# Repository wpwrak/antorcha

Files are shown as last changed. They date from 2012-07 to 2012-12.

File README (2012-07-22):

Antorcha - A LED-based signal device
====================================

...

Directory placement
-------------------

Antorcha makes extensive use of libraries and header of the ben-wpan
project. For this, the top-level directory of the ben-wpan project must
be in the same directory as the top-level directory of Antorcha. E.g.,

/home/qi/ben-wpan/
/home/qi/antorcha/

Avrdude configuration
---------------------

Antorcha uses the atusb programming adapter from the ben-wpan project.
Since the pin positions of MISO and MOSI are swapped between ATmega32U2
and the ATmega168, we use a modified configuration entry.

It is passed to avrdude via the new -L option, available with the
Nanonote patches at

http://projects.qi-hardware.com/index.php/p/ben-blinkenlights/source/tree/master/avrdude

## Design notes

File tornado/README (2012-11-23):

Tornado - A LED-based signal device
===================================

Tornado displays text or images with a line of 64 individually
controllable LEDs. To produce 2D images, the line is manually
rotated.

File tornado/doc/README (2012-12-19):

Antorcha vs. Tornado feature comparison
---------------------------------------

Number of LEDs		32			64
Pixels			16			64
LED pitch		8 mm			5 mm
1 arc sec / pixel (1)	28 m			17 m
1 arc sec / text (2)	70 m			90 m
LED line length		25 cm			32 cm
Total stick length	63 cm			53 cm (TBD)
Outer radius		~ 90 cm			~ 80 cm (3)
Visible width		~ 100 cm		~ 110 cm (3)
Sweeps per second	~ 4, bidirectional	~ 3, unidirectional
Sweep speed (avg.)	~ 8 m/s			~ 15 m/s (3)

(1) http://en.wikipedia.org/wiki/Visual_acuity
(2) 2 text lines, 1/12 display height
(3) for chain length = 30 cm

Weight
------

Al stick: 52.5 g / 52.7 cm = ~ 1 g/cm
Chain:	44 g / 19 links = ~ 2.3 g/link
	305 mm / 21 links = 14.5 mm/link
	1.6 g/cm
Attachment (screw, washers, nut): 2.3 g
End cap: 1.54 g
Cable:	1.74 g / 382 mm
	group of 3: ~ 0.14 g/cm
LED PCB: 4.1 g
CPU PCB: 4.5 g

Not included in the weight calculation:
- glue
- adhesive tapes
- isolation tapes
- cable binders (if any)
- heat-shrink tubing
- cables/wires for inter-board connections

Update rate
-----------

For square pixels we need one update every 5 mm. With the edge moving
at 15 m/s, that's one update every 1/3000 s. If we assume that,
including overhead, each 64 bit shift and latch takes about 100 clock
cycles, the serial bus needs to run at no less than 300 kHz.

sclk-1123.png shows the ~250 ns clock pulse generated by the current
test firmware. CH2 (blue) is signal entering the first LED module,
CH1 (yellow) is the signal exiting the last module. The absence of
degradation in a 250 ns pulse suggests that we can go as fast as the
MCU is able to.

Image size
----------

With a radius of 80 cm the circumference is roughly 5000 mm.
In order to obtain square pixels at the outer radius, we therefore
need 1000 lines per rotation, irrespective of speed. Each line
consists of 64 pixels or 8 bytes of data. Therefore, the full disc
needs roughly 8 kB of data while a quarter disc needs 2 kB.

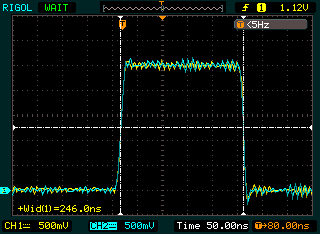
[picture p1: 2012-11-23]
tornado/doc/sclk-1123.png

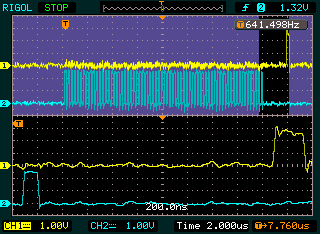
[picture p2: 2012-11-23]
tornado/doc/lclk-1123.png

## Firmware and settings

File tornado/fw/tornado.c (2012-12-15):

#include <stdbool.h>
#include <stdint.h>

#include <avr/interrupt.h>
#include <avr/pgmspace.h>
#define F_CPU   8000000UL
#include <util/delay.h>

#include "io.h"
#include "led.h"
#include "mmc.h"
#include "accel.h"


#define	HIGH(port) \
	(MASK(port, CARD_nPWR) | \
	MASK(port, SW_N) | MASK(port, SW_E) | MASK(port, SW_S) | \
	MASK(port, SW_W) | MASK(port, SW_SW))

#define	OUTPUTS(port) \
	(MASK(port, CARD_nPWR) | MASK(port, CARD_CLK) | \
	MASK(port, LED_DS) | MASK(port, LED_LCLK) | MASK(port, LED_SCLK))


#if 0

/*
 * @@@ For testing, connect the LED bar via the 8:10 card slot, so that it
 * can be disconnected without soldering.
 */

#define	SCLK	CARD_DAT1
#define	LCLK	CARD_DAT0
#define	DS	CARD_CLK
#define	VDD	CARD_CMD

#else

#define	SCLK	LED_SCLK
#define	LCLK	LED_LCLK
#define	DS	LED_DS

#endif


static void send(uint8_t pattern[N_LEDS/8])
{
	uint8_t i, j, mask;

	for (i = 0; i != N_LEDS/8; i++) {
		mask = 1;
		for (j = 0; j != 8; j++) {
			if (pattern[i] & mask)
				SET(DS);
			else
				CLR(DS);
			SET(SCLK);
			CLR(SCLK);
			mask <<= 1;
		}
	}
	SET(LCLK);
	CLR(LCLK);
}


static inline void admux(bool x)
{
	ADMUX =
	    1 << REFS0 |	/* Vref is AVcc */
	    (x ? ADC_X : ADC_Y);
}


static inline void adcsra(bool start)
{
	/*
	 * The ADC needs to run at clkADC <= 200 kHz for full resolution.
	 * At clkADC = 125 kHz, a conversion takes about 110 us.
	 */
	ADCSRA =
	    1 << ADEN |		/* enable ADC */
	    (start ? 1 << ADSC : 0) |
	    1 << ADIE |         /* enable ADC interrupts */
	    6;                  /* clkADC = clk/64 -> 125 kHz */
}


static uint16_t adc(bool x)
{
	adcsra(0);
	admux(x);
	adcsra(1);
	while (ADCSRA & (1 << ADSC));
	return ADC;
}


#define	E_SHIFT	8	/* ~ 0.06 */
#define	M_SHIFT	11	/* ~ 2/sample_rate */

#define	HYSTERESIS	9	/* 1 g / 3 */


static const uint8_t img[] PROGMEM = {
	#include "img.inc"
};


static uint8_t one[LED_BYTES] =
    { 0xff, 0xff, 0xff, 0xff, 0xff, 0xff, 0xff, 0xff };

static volatile uint16_t sample_t = 0, sample_v;


static void zxing(uint16_t x, uint16_t y)
{
	static uint32_t e = (uint32_t) 512 << E_SHIFT;
	static uint32_t m = (uint32_t) 512 << M_SHIFT;
	int16_t d;
	static bool up = 0;
	static bool on = 0;
	static const prog_uint8_t *p;
	static uint16_t cols = 0;

	sample_t++;
	sample_v = x;

	e = x+(e-(e >> E_SHIFT));
	m = x+(m-(m >> M_SHIFT));
	d = (e >> E_SHIFT)-(m >> M_SHIFT);
	if (up) {
		if (d < -HYSTERESIS)
			up = 0;
	} else {
		if (d > HYSTERESIS) {
			up = 1;
			p = img;
			cols = sizeof(img)/LED_BYTES;
			on = 1;
		}
	}
	if (cols) {
		led_show_pgm(p);
		p += 8;
		cols--;
	} else {
		led_off();
	}
}


static void panic(void)
{
	cli();
	while (1) {
		led_show(one);
		_delay_ms(100);
		led_off();
		_delay_ms(100);
	}
}


int main(void)
{
	PORTB = HIGH(B);
	PORTC = HIGH(C);
	PORTD = HIGH(D);
	DDRB = OUTPUTS(B);
	DDRC = OUTPUTS(C);
	DDRD = OUTPUTS(D);

	CLR(CARD_nPWR);
	CLR(SCLK);
	CLR(LCLK);
	OUT(SCLK);
	OUT(LCLK);
	OUT(DS);

#ifdef VDD
	SET(VDD);
	OUT(VDD);
#endif

	led_init();

#if 0
	led_show(one);

	if (!mmc_init())
		panic();
	if (!mmc_begin_write(0))
		panic();

	uint16_t n = 0;

	for (n = 0; n != 512; n += 2) {
		mmc_write(n);
		mmc_write(n >> 8);
	}

	if (!mmc_end_write())
		panic();

	if (!mmc_begin_write(n))
		panic();

	for (; n != 1024; n += 2) {
		mmc_write(n);
		mmc_write(n >> 8);
	}

	if (!mmc_end_write())
		panic();

	_delay_ms(1000);

	led_off();

	while (1);
#endif

#if 1
	uint16_t last_t = 0;
	uint32_t n = 0;

	sample = zxing;
	/* MMC doesn't work when running from battery, probably because we
	   have no regulation. Just disable it for now. */
#if 0
	if (!mmc_init())
		panic();
#endif
	accel_start();
	sei();
while (1);
	while (1) {
		uint16_t t, v;

		if (!(n & 511)) {
			if (n && !mmc_end_write())
				panic();
			if (!mmc_begin_write(n))
				panic();
		}

#if 0
	t = n;
	v = 0;
#else
		do {
			cli();
			t = sample_t;
			v = sample_v;
			sei();
		}
		while (t == last_t);
#endif

		last_t = t;
		mmc_write(t);
		mmc_write(t >> 8);
		mmc_write(v);
		mmc_write(v >> 8);
		n += 4;
	}
#endif

#if 0
	static uint8_t p[LED_BYTES];
	uint8_t mode = 0;
	uint16_t n = 0, v;

	while (1) {
		while (!PIN(SW_SW));
		if (!PIN(SW_N))
			mode = 0;
		if (!PIN(SW_E))
			mode = 1;
		if (!PIN(SW_S))
			mode = 2;
		switch (mode) {
		case 1:
			n = adc(0);
			p[0] = n;
			p[1] = n >> 8;
			p[2] = p[3] = p[4] = p[5] = p[6] = p[7] = 0;
			send(p);
			break;
		case 2:
			n = adc(1);
			p[0] = n;
			p[1] = n >> 8;
			p[2] = p[3] = p[4] = p[5] = p[6] = p[7] = 0;
			send(p);
			break;
		default:
			v = 63-n;
			if (n & 64)
				p[(v >> 3) & 7] &= ~(1 << (v & 7));
			else
				p[(v >> 3) & 7] |= 1 << (v & 7);
			led_show(p);
			n++;
		}
		_delay_ms(100);
	}
#endif
}

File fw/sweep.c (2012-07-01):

/*
 * fw/image.c - Image sweep
 *
 * Written 2012 by Werner Almesberger
 * Copyright 2012 Werner Almesberger
 *
 * This program is free software; you can redistribute it and/or modify
 * it under the terms of the GNU General Public License as published by
 * the Free Software Foundation; either version 2 of the License, or
 * (at your option) any later version.
 */


#include <stdbool.h>
#include <stdint.h>

#include <avr/io.h>
#include <avr/interrupt.h>

#include "image.h"
#include "sweep.h"


volatile bool sweeping = 0;


static volatile uint32_t t_up;	/* uptime, in timer ticks (wraps in 4295 s) */
static volatile uint32_t t_sw;	/* cumulative number of timer ticks in sweep */

static uint16_t wait_periods;	/* number of periods to wait before image */
static uint16_t wait_period;	/* ticks in wait period */
static uint16_t wait_short;	/* ticks to wait after periods */

static uint16_t pixel_ticks;	/* number of ticks per pixel */
static const struct line *curr_line;
static const struct line *end_line;
static bool forward;


ISR(TIMER1_OVF_vect)
{
	uint16_t t;

	/* update the time counters */

	t = ICR1;
	t_sw += t;
	t_up += t;

	/* if at the end of the image, only update the time */

	if (curr_line == end_line) {
		PORTB &= 0x3f;
		PORTC = 0;
		PORTD = 0;
		ICR1 = 0xffff;
		sweeping = 0;
		return;
	}

	/* wait before starting the image */

	if (wait_periods) {
		if (!--wait_periods)
			ICR1 = wait_short;
		return;
	}

	/* if done, lights out and slow down */

	/* output the next line */

	set_line(*curr_line);

	/* move to the next line */

	if (forward)
		curr_line++;
	else
		curr_line--;

	/* wait until the next pixel */

	ICR1 = pixel_ticks;
}


uint32_t uptime_irq(void)
{
	uint32_t t;

	t = t_up+TCNT1;
	if (TIFR1 & TOV1)
		t += ICR1;
	return t;
}


uint32_t uptime(void)
{
	uint32_t a, b;
	uint16_t d;

	do {
		cli();
		a = t_up;
		d = TCNT1;
		cli();
		b = t_up;
		sei();
	}
	while (a != b);
	return a+d;
}


void sweep_image(const struct sweep *sweep)
{
	uint32_t t;

	/* calculate start time */

	t = uptime();
	if (sweep->start_ticks <= t)
		return;
	t = sweep->start_ticks-t;

	TCCR1B = 0;	/* stop the timer */

	cli();

	/* shut down all the LEDs, in case we're still in a sweep */

	PORTB &= 0x3f;
	PORTC = 0;
	PORTD = 0;

	/* image pointers and sweep direction */

	forward = sweep->forward;
	if (forward) {
		curr_line = image+sweep->left;
		end_line = image+sweep->right+1;
	} else {
		curr_line = image+sweep->right;
		end_line = image+sweep->left-1;
	}

	/* timing parameters */

	pixel_ticks = sweep->pixel_ticks;
	wait_periods = t >> 16;
	if (wait_periods) {
	 	wait_short = t;
		wait_period = 0xffff;

		/*
		 * Make sure we have plenty of time to update ICR1 after an
		 * interrupt.
		 */
		if (wait_short < 256) {
			wait_period -= 128;
			wait_short += wait_periods << 7;
		}
		ICR1 = wait_period;
	} else {
	 	ICR1 = t;
	}

	/* prepare the hardware timer */

	t_sw = 0;		/* reset the time */
	TCNT1 = 0;
	TIFR1 = 1 << TOV1;	/* clear interrupt */
	
	/* start the timer */

	TCCR1B =
	    1 << WGM13 |	/* WG Mode 14, continued */
	    1 << WGM12 |
	    1 << CS11;		/* clkIO/8 */

	sweeping = 1;

	sei();
}


void sweep_init(void)
{
	TCCR1A =
	    1 << WGM11;		/* WG Mode 14 (Fast PWM to ICR1) */

	TCNT1 = 0;

	TIMSK1 = 1 << TOIE1;	/* enable timer interrupts */
}

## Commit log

2012-06-12 Initial commit
    First design iteration, with layout.
    [accel.sch, antorcha.brd, antorcha.sch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]
2012-06-12 antorcha/hw/: improve antenna, grounding, trace widths, etc.
    [accel.sch, antorcha.brd, antorcha.sch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]
2012-06-12 hw/antorcha.brd: move control board such that we can duplicate it
    [antorcha.brd]
2012-06-16 hw/: assorted schematics cleanup
    [accel.sch, antorcha.brd, control.sch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]
2012-06-16 hw/: pull SLP_TR down, not up
    The transceiver happily jumped right into sleep mode after leaving
    reset ...
    [antorcha.brd, rf.sch]
2012-06-18 fw/: addition of boot loader (WIP) and assorted cleanup and improvements
    The boot loader currently uses the protocol switch intended for the
    application. This makes it too big to fit in the very limiting
    constraints the ATmega168 poses - and there's not even cryptographic
    authentication yet. We'll have to dumb it down quite a bit.
    [boot.c]
2012-06-18 RESET protocol to jump from application to boot loader without power cycling
    [boot.c, proto.h]
2012-06-20 fw/sweep.c: use ICR1 instead of double-buffered OCR1A; set pixel_ticks
    Our timing is now accurate within a measured 0.5% on the test device,
    which is well within the specified 1% of the calibrated RC oscillator.
    [sweep.c]
2012-06-21 fw/accel.c: keep track of uptime and return it with uptime() (untested)
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2012-06-21 fw/spi.c: clean up code and add option for running at fosc/2 instead of fosc/4
    Not enabled yet. There's a RF comm regression elsewhere that needs fixing
    first.
    [spi.c]
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2012-06-21 fw/accel.c: fix update() add interrupt-friendly update_irq()
    Still untested.
    [sweep.c]
2012-06-21 fw/accel.c: use timer 0 to trigger a pair of conversions (X/Y) only every 1 ms
2012-06-21 fw/sample.c: fix logic in handler() and filter incomplete samples
    An incomplete sample would be an X value followed by another X value,
    or Y followed by Y. Not entirely sure why this happens in the first
    place, but it does happen.
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2012-06-21 tools/: exit from sample mode by pressing Q or by closing the window
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2012-06-21 fw/sample.c (handler): set the time in samples (was set to zero, for debugging)
2012-06-21 tools/antorcha.c (samples): show the timestamp when printing sample values
2012-06-21 fw/spi.c (spi_init): raise SPI speed from fosc/4 to fosc/2
2012-06-21 fw/spi.c (spi_init): revert the SPI speed increase (caused instability)
    Some more testing showed that transfers would get stuck after ~40 packets.
    Need to find out what happened before trying this again.
    [spi.c]
2012-06-22 fw/accel.c (adcsra): let ADC run at 125 kHz (instead of 67.5 kHz)
2012-06-23 tools/antorcha.c (samples): move reading of X/Y samples to shared function
2012-06-23 tools/: -S now dumps samples to stdout; -S -S produces graphical output
2012-06-23 fw/spi.c: explain why we probably can't reach fosc/2 = 4 MHz
2012-06-24 fw/sweep.c (TIMER1_OVF_vect): turn off the LEDs when done
    This means that the image no longer has to contain terminating all-zero rows.
    [sweep.c]
2012-06-27 fw/proto.h: assorted cleanup and corrections
    - remove struct params.clkT_period
    - correct size of tp_*_start
    - correct size of tp_*_pix
    - move MAX_LINES from image.h to proto.h (to ease sharing with tools)
    Things now work a bit differently from how they were planned back when
    clkT_period was added.
    [proto.h]
2012-06-28 fw/antorcha.c (main): allow a new sweep to preempt an active sweep
    Waiting until the current sweep finished could delay the next sweep
    (without cancelling it), confusing the timing.
2012-06-30 tools/libtxt/: make_font takes ownership of the image
    This way, we don't need to track/free the image separately.
2012-06-30 tools/libtxt/edit.c (text2edit): disentangle confused logic of "e" variable
    We used it for the whole list and the current element, which didn't work
    very well.
2012-07-01 doc/BOM-ME: BOM for mechanical parts, with examples from www.easy.com.ar
2012-07-01 fw/sweep.c (set_line): export line setting (output on LEDs) function
2012-07-01 fw/accel.c (measure_ref): GND and Vbg measurement function (for diagnostics)
2012-07-01 fw/: add DIAG protocol (supply voltage measurement, for diagnostics)
2012-07-01 fw/diag.c: fix and improve DIAG function
    - we didn't send ACKs for the authentication packets
    - take multiple samples (4)
    - add 100 ms delay to let the battery voltage settle
    [proto.h]
2012-07-01 clean up diagnostic more and make it more robust
    A number of changes:
    - don't enable interrupts, since they often cause hangs (not sure why)
    - remove GND measurement
    - wait 100 us between AMUX setup and start of conversion, to let input
    settle
    - reduce delay between line setup and samping from 100 ms to 50 ms,
    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
2012-07-01 tools/ant-cl/ant-cl.c (send_diag): print the requested pattern (if verbose)
2012-07-06 fw/antorcha.c (main): reset the RF subsystem if it's idle for ~1 second
    For some reason, DIAG often stalls the RF subsystem. The periodic reset
    brings it back to life.
2012-07-06 fw/diag.c (do_diag): update explanation why we don't enable interrupts
    The hang was caused by the RF subsystem getting into trouble. The
    interrupts still cause some issues, so we don't enable them yet.
    A system reset (ant-cl -R) will clean up everything nicely.
2012-07-31 fw/accel.c (adcsra): correct typo in comment
    [accel.c]
2012-11-04 whirl/: LED board for new experimental design variant
    [whirl.brd, whirl.sch]
2012-11-04 whirl/: add component values
    [whirl.sch]
2012-11-04 whirl/whirl.brd: clean up layout; upgrade 3V3 to "Power"; fatten power vias
    [whirl.brd]
2012-11-05 whirl/*: move to whirl/led/; also rename whirl.* to led.*
    [led.brd, led.sch]
2012-11-05 whirl/cpu/: add CPU module for "whirl" design
    [cpu.brd, cpu.sch]
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2012-11-06 whirl/cpu/: flip CON2 (to LEDs) and increase width of power traces
    For 2 A we need a trace width of about 0.4 mm, not 0.3 mm.
    [cpu.brd, cpu.sch]
2012-11-07 fw/pcb/: Makefile and mkmk for PCB making (forgot to add them)
2012-11-16 whirl/fw/: skeleton test firmware (doesn't do anything useful yet)
    [boot.c, io.h]
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2012-11-17 whirl/fw/: design testing: acceleration sensor
    Switch selects display move: N = counter, E = WE axis; S = NS axis; SW = hold
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2012-11-19 tornado/led/led.brd: change label from "WHIRL" to "TORNADO"
    [led.brd]
2012-11-23 tornado/fw/tornado.c: use LED_* to communicate with LED bar; update demo
    Instead of a counter, which worked okay with 16 LEDs but is useless with
    all 64 of them, we now show a filling/emptying bar. The update speed is
    high enough that rotation results in about a quarter-circle pattern.
2012-11-23 tornado/doc/mech.fpd: increase length of bottom part of stick from 5 cm to 12 cm
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2012-11-23 tornado/: use UART in SPI mode to send LED patterns (at 4 Mbps)
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2012-12-04 tornado/fw/tornado.c: add test mode indicating positive zero-crossing
    Works sometimes but often produces false zero-crossings, particularly
    if there are many chain "jumps".
2012-12-04 tornado/fw/txt/: tools for text conversion
    txt2xbm: convert text to XBM, using ghostscript
    stretch: resample XBM with rotation correction (x-axis only)
    xbm2gp: convert XBM to gnuplot, taking into account rotation
    plot: plot xbm2gp output
    t: run all the above to display "TEST"
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2012-12-04 tornado/fw/: add MMC driver (WIP, based on Mass Storage for V-USB by "lleeloo")
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2012-12-05 tornado/fw/mmc.c (mmc_wait): add 1 ms delay to wait loop
    MMC-SPI specifies a card delay of up to 100 ms, which is easier to match
    with an explicit delay than with a loop count.
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2012-12-09 tornado/fw/sim/alg.c: tune EWMA weights; correct sample rate for simulation
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2012-12-09 tornado/fw/tornado.c: experimental code to log ADC samples to memory card
    For a yet unknown reason, writing to the card fails if also processing
    the samples. Maybe it's some side-effect of switching the LEDs.
    [tornado.c]
2012-12-25 tornado/cpu/: new version of the CPU board (WIP)
    Differences:
    - a bit smaller, 42.25 x 22.5 mm. The old version was 43.75 x 25.25 mm
    - NXP LPC1112FHN33/202 MCU (Cortex-M0)
    - step-down converter for the 3.3 V supply
    - all-digital 3D acceleration sensor
    - one local LED
    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
    [cpu.brd, cpu.sch]
2012-12-25 tornado/cpu/cpu.brd: improve 3V3 routing
    [cpu.brd]
2012-12-27 tornado/cpu/cpu.sch: split overly crowded sheet into two
    [cpu.sch, per.sch]
2012-12-27 tornado/cpu/: rearrange things and fix ERC problems
    [cpu.sch, per.sch]
2012-12-27 tornado/led/: update schematics for new power distribution
    [led.sch, leds.sch]
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2012-12-27 tornado/led/: layout for new LED board version
    [led.brd, led.sch, leds.sch]
2012-12-27 tornado/led/led.brd: clean up layout
    [led.brd]
2012-12-27 tornado/cpu/cpu.brd: include subsystem name (CPU) in text label
    Also update the date code.
    [cpu.brd]
2012-12-27 tornado/cpu/cpu.brd: make connection to the MCU's GND pad straighter
    [cpu.brd]
2012-12-28 tornado/cpu/cpu.sch (CON3): nISP and nRESET were swapped
    [cpu.sch]
